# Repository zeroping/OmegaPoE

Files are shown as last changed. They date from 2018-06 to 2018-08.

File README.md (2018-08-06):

# OmegaPoE
A Power-over-Ethernet Dock for the Onion Omega board

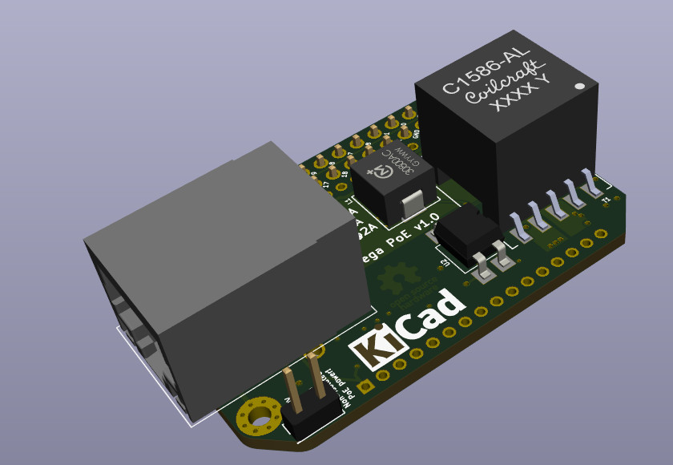
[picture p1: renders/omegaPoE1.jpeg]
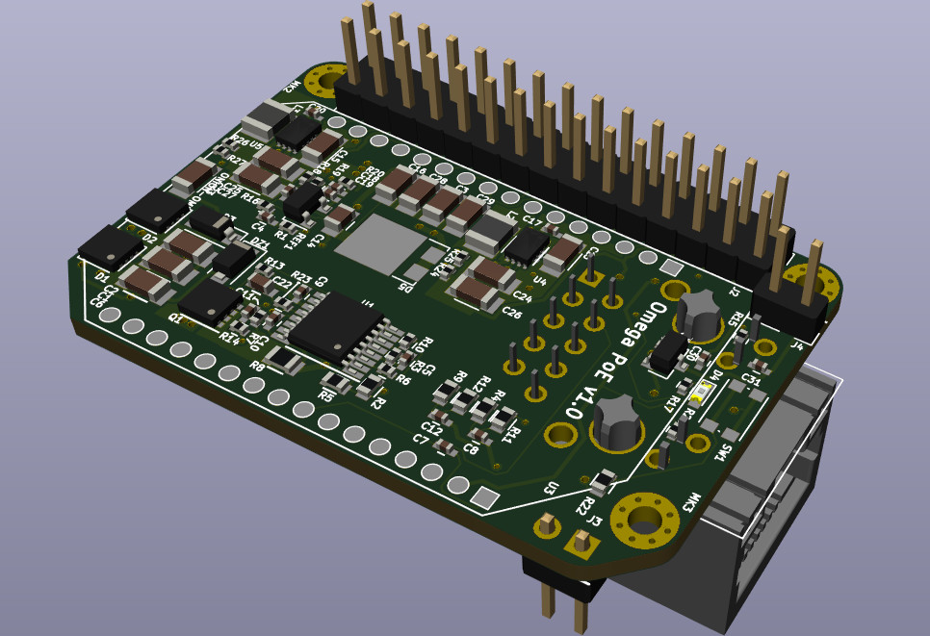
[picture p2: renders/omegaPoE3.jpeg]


This is a KiCad circut board design for an Onion Omega "dock" that connects the Onion via Ethernet, while also powering it via 802.3af Power-over-Ethernet.

The Onion Omega is a cheap ($10.75) linux single-board computer, and supports WiFi and Ethernet. For more information on the Onion Omega, see [the Onion Omega site](http://onion.io/omega2/).

This board is designed to be as small as possible while still providing an isolated 15-watt PoE supply. The 48 VDC power from PoE is converted into 12 V using a TI LM5070 in a flyback configuration. The 12 V is further stepped down to 5 V and 3.3 V using two TPS62135x DC-DC buck converters. 12 V was chosen to allow running 12V perhierals off of the board, such as 12V LED lighing strips. 

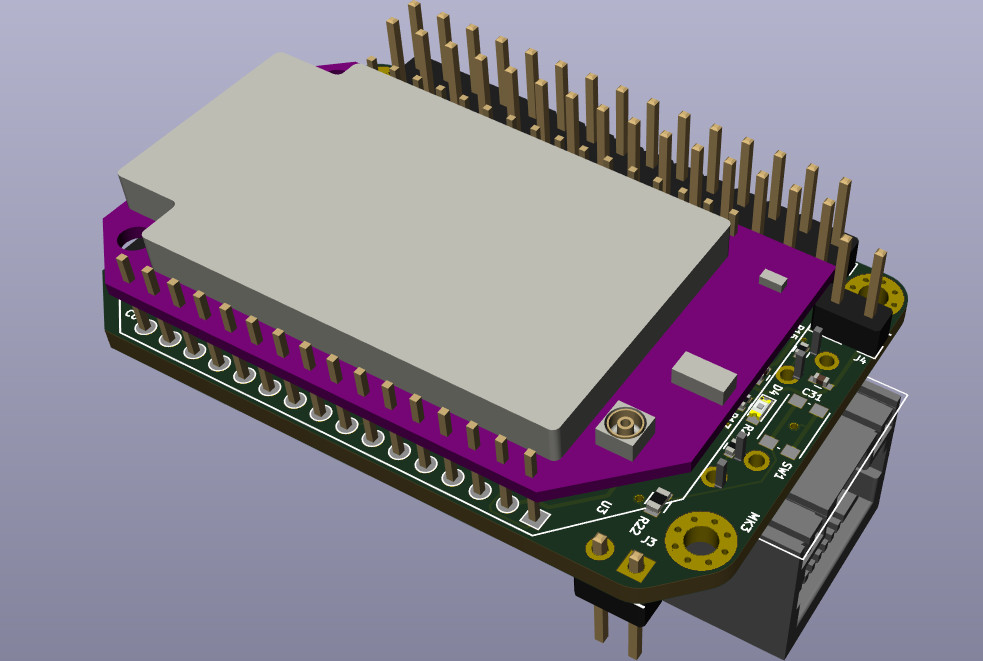
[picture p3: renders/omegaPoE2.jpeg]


## Status
Four prototype boards have been built, and they work. There are some issues to work out and fixes to commit, but here's the v1 board run:

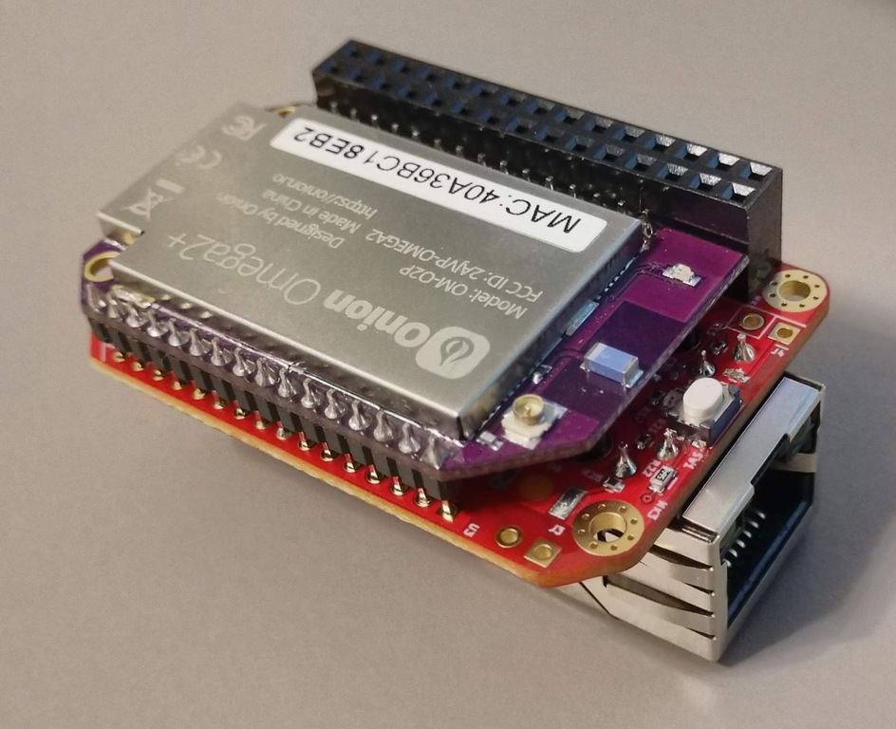
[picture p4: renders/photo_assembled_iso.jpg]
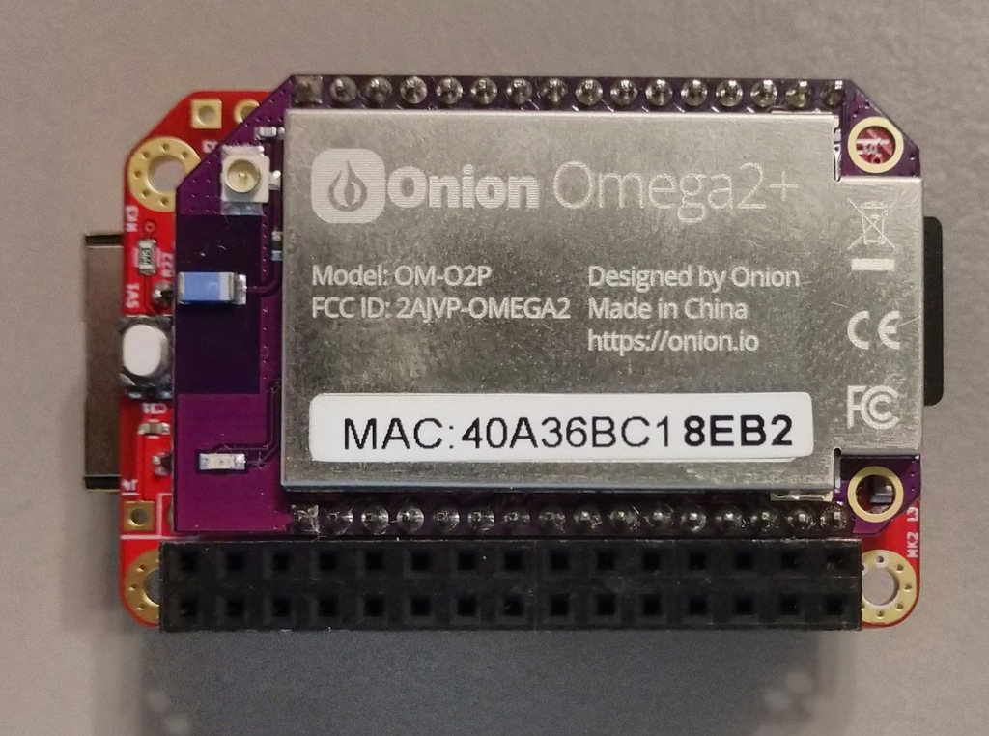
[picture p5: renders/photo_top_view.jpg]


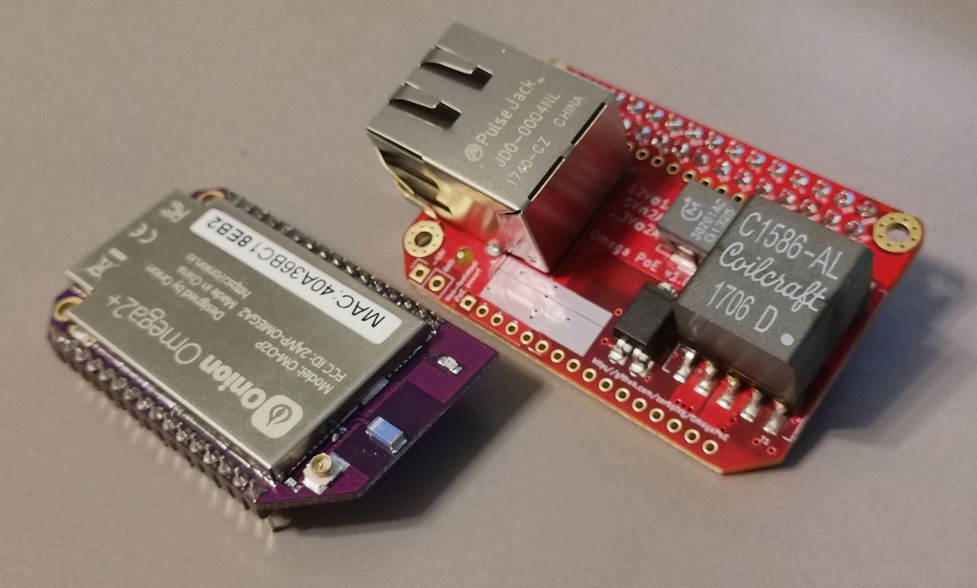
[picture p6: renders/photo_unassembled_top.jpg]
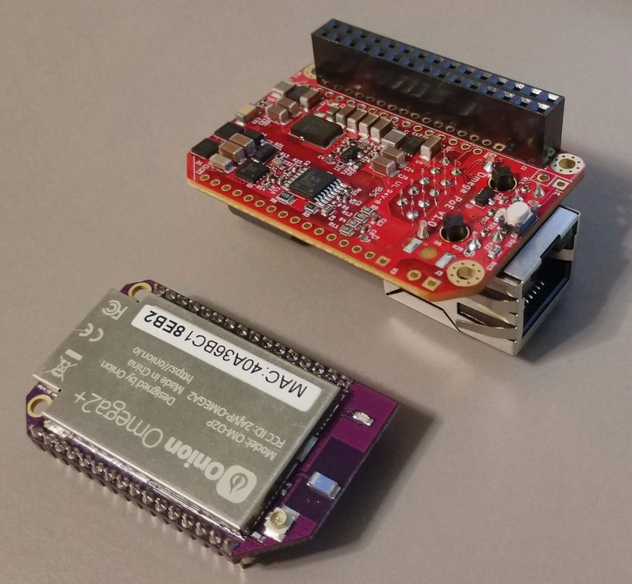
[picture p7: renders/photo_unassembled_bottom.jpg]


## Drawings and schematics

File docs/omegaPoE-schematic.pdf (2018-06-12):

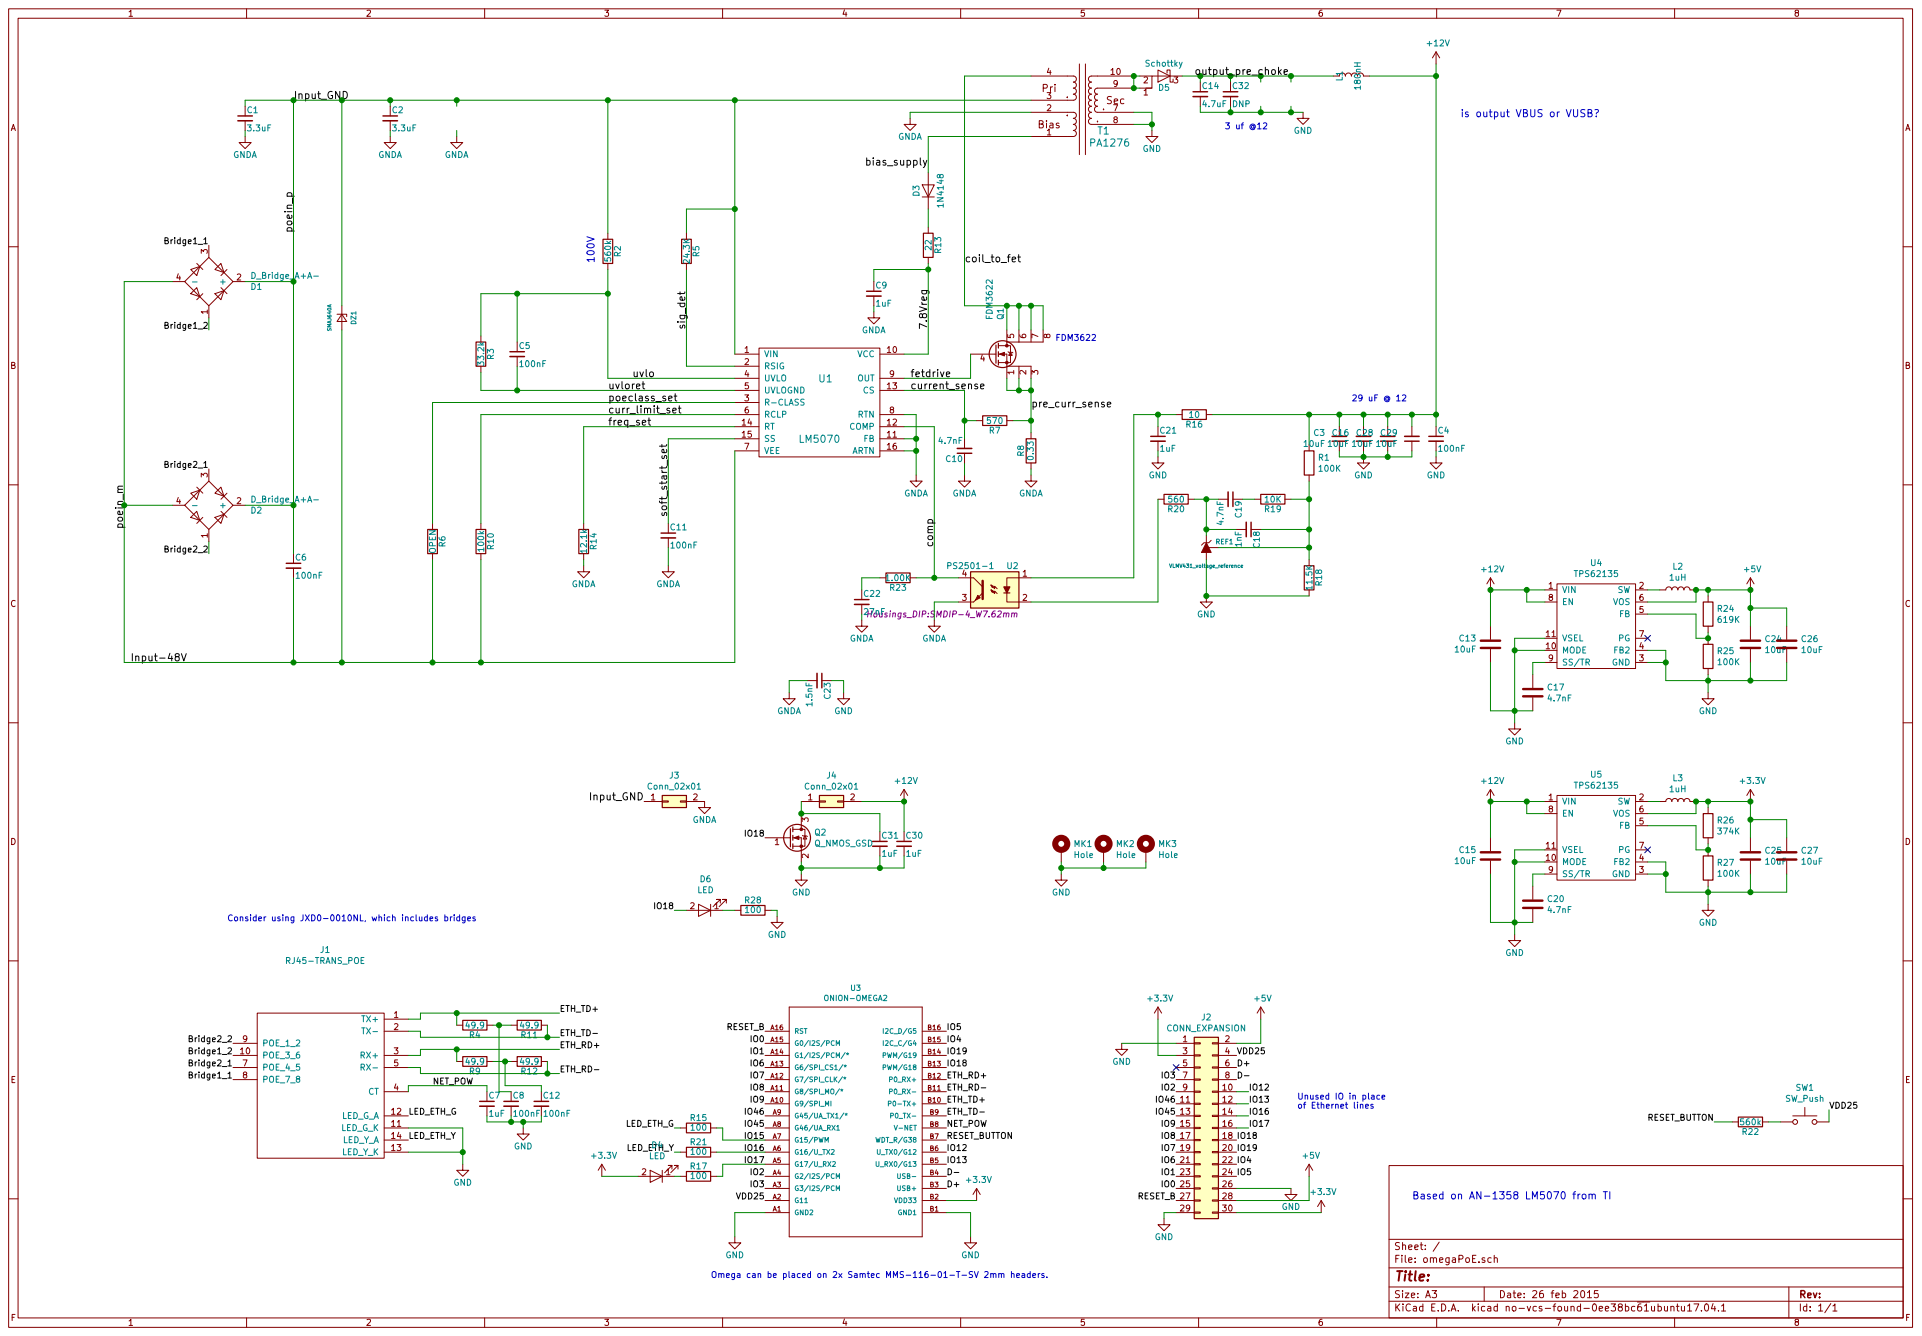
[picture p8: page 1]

is output VBUS or VUSB?

Based on AN-1358 LM5070 from TI poein_p poein_m

1uF Consider using JXD0-0010NL, which includes bridges

File: omegaPoE.sch Sheet: /

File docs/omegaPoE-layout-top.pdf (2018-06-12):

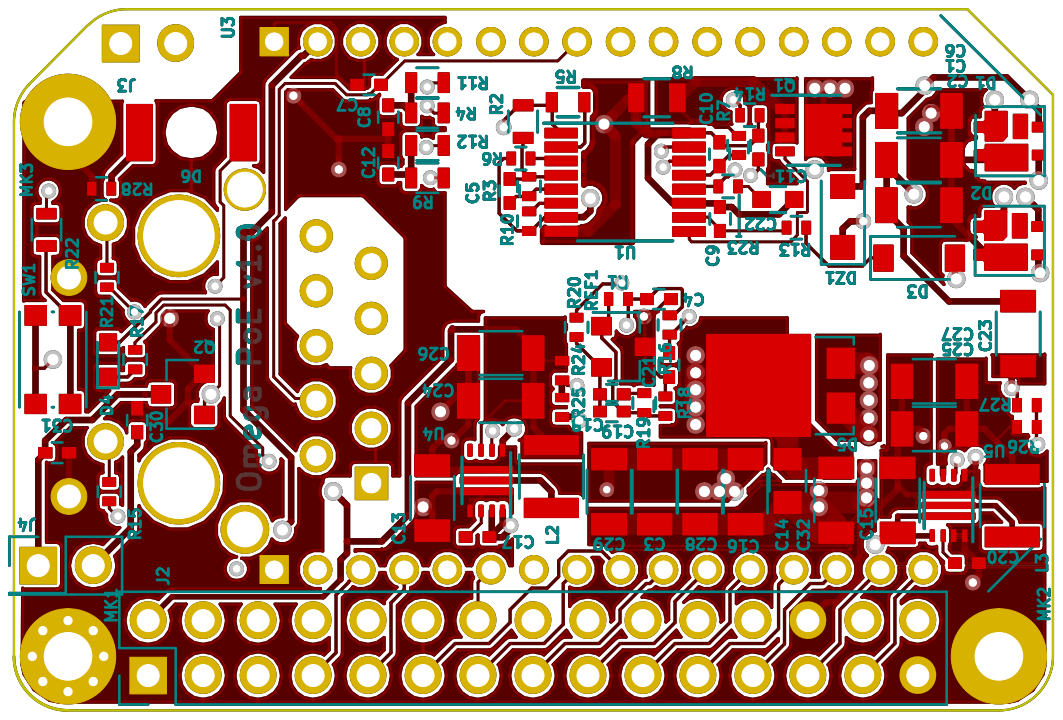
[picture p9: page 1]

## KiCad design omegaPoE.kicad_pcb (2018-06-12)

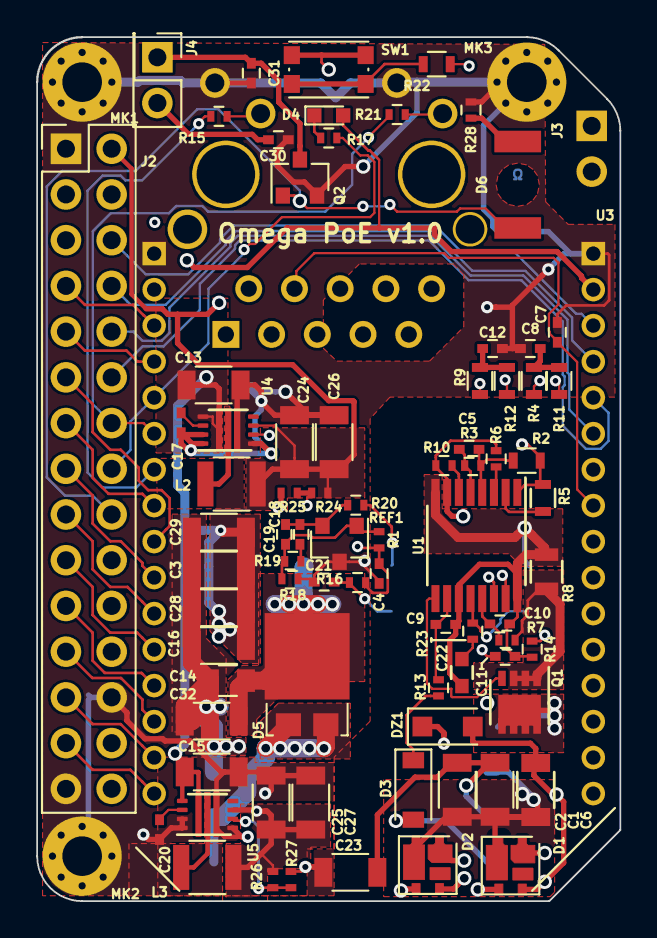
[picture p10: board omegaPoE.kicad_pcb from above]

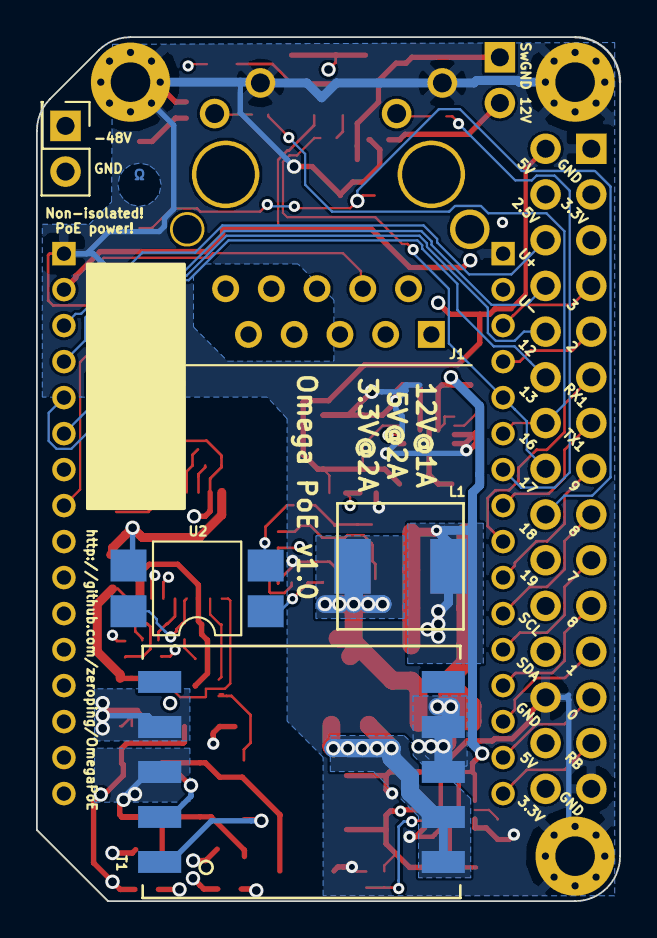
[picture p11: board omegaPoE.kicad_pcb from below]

Board: 4 copper layers, 32.4 x 48.0 mm, 87 parts (5 on the bottom side), 77 nets.

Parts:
C1, C2: 3.3uF; C_1206
C3, C13, C15, C16, C24, C25, C26, C27, C28, C29: 10uF; C_1206
C4, C5, C8, C11, C12: 100nF; C_0402
C6: 100nF; C_1206
C7, C9, C21, C30, C31: 1uF; C_0402
C10, C19: 4.7nF; C_0402
C14: 4.7uF; C_0805
C17, C20: 4.7nF; C_0402_NoSilk
C18: 1nF; C_0402
C22: 27nF; C_0603
C23: 1.5nF; C_1206
C32: DNP; C_1206
D1, D2: D_Bridge_A+A-; U-DFN303-4
D3: 1N4148; D_SOD-123
D4: LED; LED_0603
D5: Schottky; TO-277A
D6: LED; LED_reverse_gull
DZ1: SMAJ640A; D_SOD-123F
J1: RJ45-TRANS_POE; JD0-0004NL
J2: CONN_EXPANSION; Pin_Header_Straight_2x15_Pitch2.54mm
J3, J4: Conn_02x01; Pin_Header_Straight_2x01_Pitch2.54mm
L1: 180nH; Murata-3000A-series
L2, L3: 1uH; L_1210
MK1, MK2, MK3: Hole; MountingHole_2.2mm_M2_Pad_Via
Q1: FDM3622; DFN-8-1EP_3x3mm_Pitch0.65mm-mod
Q2: Q_NMOS_GSD; SOT-23
R1, R25, R27: 100K; R_0402_NoSilk
R2, R22: 560k; R_0603
R3: 33.2k; R_0402
R4, R9, R11, R12: 49.9; R_0603
R5: 24.3K; R_0603
R6: OPEN; R_0402
R7: 570; R_0402
R8: 0.33; R_0805
R10: 100k; R_0402
R13: 22; R_0402
R14: 12.1k; R_0402
R15, R17, R21, R28: 100; R_0402
R16: 10; R_0402
R18: 11.5K; R_0402
R19: 10K; R_0402
R20: 560; R_0402
R23: 1.00K; R_0402
R24: 619K; R_0402_NoSilk
R26: 374K; R_0402_NoSilk
REF1: VLMV431_voltage_reference; SOT-23
SW1: SW_Push; SW_SPST_KMR2
T1: PA1276; Pulse_PA1269
U1: LM5070; TSSOP-16_4.4x5mm_Pitch0.65mm
U2: PS2501-1; SMDIP-4_W7.62mm
U3: ONION-OMEGA2; ONION-OMEGA
U4, U5: TPS62135; DFN-8-3EP_3x2mm_Pitch0.5mm

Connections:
+3V3: C25.1, C27.1, D4.2, J2.3, J2.30, L3.2, R26.1, U3.B2, U5.6
+5V: C24.1, C26.1, J2.2, J2.28, L2.2, R24.1, U4.6
+12V: C3.2, C4.1, C13.2, C15.2, C16.2, C28.2, C29.2, C30.1, J4.2, L1.2, R1.1, R16.1, U4.1, U4.8, U5.1, U5.8
/7.8Vreg: C9.1, R13.2, U1.10
/Bridge1_1: D1.3, J1.8
/Bridge1_2: D1.1, J1.10
/Bridge2_1: D2.3, J1.7
/Bridge2_2: D2.1, J1.9
/D+: J2.6, U3.B3
/D-: J2.8, U3.B4
/ETH_RD+: J1.3, R9.2, U3.B12
/ETH_RD-: J1.5, R12.1, U3.B11
/ETH_TD+: J1.1, R4.2, U3.B10
/ETH_TD-: J1.2, R11.1, U3.B9
/IO0: J2.25, U3.A15
/IO1: J2.23, U3.A14
/IO2: J2.9, U3.A4
/IO3: J2.7, U3.A3
/IO4: J2.22, U3.B15
/IO5: J2.24, U3.B16
/IO6: J2.21, U3.A13
/IO7: J2.19, U3.A12
/IO8: J2.17, U3.A11
/IO9: J2.15, U3.A10
/IO12: J2.10, U3.B6
/IO13: J2.12, U3.B5
/IO15: R15.1, U3.A7
/IO16: J2.14, R21.1, U3.A6
/IO17: J2.16, R17.1, U3.A5
/IO18: D6.2, J2.18, Q2.1, U3.B13
/IO19: J2.20, U3.B14
/IO45: J2.13, U3.A8
/IO46: J2.11, U3.A9
/Input-48V: C6.2, D1.4, D2.4, DZ1.2, R6.2, R10.2, U1.7
/Input_GND: C1.1, C2.1, C6.1, D1.2, D2.2, DZ1.1, J3.1, R2.1, R5.1, T1.3, U1.1
/LED_ETH_G: J1.12, R15.2
/LED_ETH_Y: J1.14, R21.2
/NET_POW: C7.1, J1.4, U3.B8
/RESET_B: J2.27, U3.A16
/RESET_BUTTON: R22.2, U3.B7
/VDD25: J2.4, SW1.2, U3.A2
/bias_supply: D3.2, T1.1
/coil_to_fet: Q1.5, Q1.6, Q1.7, Q1.8, T1.4
/comp: R23.1, U1.12, U2.4
/curr_limit_set: R10.1, U1.6
/current_sense: C10.2, R7.2, U1.13
/fetdrive: Q1.4, U1.9
/freq_set: R14.1, U1.14
/output_pre_choke: C14.1, C32.1, D5.3, L1.1
/poeclass_set: R6.1, U1.3
/pre_curr_sense: Q1.1, Q1.2, Q1.3, R7.1, R8.2
/sig_det: R5.2, U1.2
/soft_start_set: C11.1, U1.15
/uvlo: C5.1, R2.2, R3.1, U1.4
/uvloret: C5.2, R3.2, U1.5
GND: C3.1, C4.2, C7.2, C8.2, C12.2, C13.1, C14.2, C15.1, C16.1, C17.2, C20.2, C21.2, C23.1, C24.2, C25.2, C26.2, C27.2, C28.1, C29.1, C30.2, C31.2, C32.2, J1.11, J1.13, J2.1, J2.26, J2.29, MK1.1, MK2.1, MK3.1, Q2.2, R18.2, R25.2, R27.2, R28.1, REF1.3, T1.7, T1.8, U3.A1, U3.B1, U4.3, U4.4, U4.10, U4.11, U5.3, U5.4, U5.10, U5.11
GNDA: C1.2, C2.2, C9.2, C10.1, C11.2, C22.2, C23.2, J3.2, R8.1, R14.2, T1.2, U1.8, U1.11, U1.16, U2.3
unnamed: C8.1, R4.1, R11.2
unnamed: C12.1, R9.1, R12.2
unnamed: C17.1, U4.9
unnamed: C18.1, R1.2, R18.1, R19.1, REF1.1
unnamed: C18.2, C19.2, R20.1, REF1.2
unnamed: C19.1, R19.2
unnamed: C20.1, U5.9
unnamed: C21.1, R16.2, U2.1
unnamed: C22.1, R23.2
unnamed: C31.1, J4.1, Q2.3
unnamed: D3.1, R13.1
unnamed: D4.1, R17.2
unnamed: D5.1, D5.2, T1.9, T1.10
unnamed: D6.1, R28.2
unnamed: L2.1, U4.2
unnamed: L3.1, U5.2
unnamed: R20.2, U2.2
unnamed: R22.1, SW1.1
unnamed: R24.2, R25.1, U4.5
unnamed: R26.2, R27.1, U5.5

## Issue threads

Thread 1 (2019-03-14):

LEDs' pupose and operation

wiyh12nf89x, 2019-03-14:
Hello. The board's LED operation is unclear to me, so I made a list of questions:

1. The ethernet port indication LEDs are connected to A5 and B13 pins. Are they now functional?
2. The official Omega Ethernet Expansion Board[[[[https://github.com/OnionIoT/Onion-Hardware/blob/master/Schematics/Omega-Ethernet-Expansion.pdf]]]] doesn't have port indication LEDs so do they work out-of-the-box as soon as Omega2 finds ethernet signals on pins B9..B12 or do you have to switch them manually by e. g. ifupdown scripts?
3. Is the connection transfer rate indication implemented (10/100Mbps)?
4. Is the data transmission indication implemented? Is it constant-frequency or the blinking frequency depend on current data transmission rate?
5. Is the posistion these LEDs them somehow hardcoded or it can be changed? E. g. if I develop my own design, can i move them to another pins?
6. What is the purpose of D4 (A5 pin) and D6 (B13 pin) LEDs?

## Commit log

2018-06-07 Initial commit of partly-finished board
    [omegaPoE.kicad_pcb, omegaPoE.sch]
2018-06-07 More cleanup, some power planes in and text fixed
    [omegaPoE.kicad_pcb, omegaPoE.sch]
2018-06-07 Mostly finished with design. Fixed lots of 3D models and some part rotations.
    [omegaPoE.kicad_pcb, omegaPoE.sch]
2018-06-09 Swapped to some cheaper parts, fixed cap selection on 12V line.
    [omegaPoE.kicad_pcb, omegaPoE.sch]
2018-06-10 Added mounting holes, shrank up board, make 12V output switched
    [omegaPoE.kicad_pcb, omegaPoE.sch]
2018-06-10 Added silkscreen
    [omegaPoE.kicad_pcb]
2018-06-11 More cleanup. Fixing silkscreen on footprints, cleaing up MPN's.
    [omegaPoE.kicad_pcb, omegaPoE.sch]
2018-06-11 Moved flyback output components to minimize EMI. Lots of power flood work.
    [omegaPoE.kicad_pcb, omegaPoE.sch]
2018-06-11 Not sure what changed - more zone cleanup, I think?
    [omegaPoE.kicad_pcb]
2018-06-12 Added rever-semount LED for testing, cleaned up MPN listings some more.
    [omegaPoE.kicad_pcb, omegaPoE.sch]
2018-06-12 Final updates before ordering
    [omegaPoE.kicad_pcb]
